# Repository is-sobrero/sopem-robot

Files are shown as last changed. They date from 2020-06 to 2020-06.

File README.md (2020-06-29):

<h1 align="center">SoPEM Robot</h1>
<div align="center">
      <a href="https://www.youtube.com/watch?v=lT5buDZkqcU&t">
     Copertina video
      </a><br>
      <i>Clicca la copertina per guardare il video di presentazione</i><br><br><br>
      
</div>

# Tabella dei contenuti
- [Introduzione](#introduzione)
- [Filosofia Open Source in ogni aspetto](#filosofia-open-source-in-ogni-aspetto)
- [Singoli componenti](#singoli-componenti)
- [Licenza](#licenza)
  - [Autori / Copyright](#autori--copyright)
  - [Dettagli licenza](#dettagli-licenza)

# Introduzione
SoPEM è un robot di tipologia rover studiato appositamente per le finali delle Olimpiadi di Robotica 2020 (anche se in lockdown).
Sfruttando materiali di riciclo, sono stati costruiti 3 robot, dall'aspetto diverso ma tutti e tre volti allo stesso scopo: monitorare i valori di PM10 delle città in modo autonomo con un sensore autocostruito con materiali di riciclo (Un LED infrarosso ricavato da un telecomando e un fotodiodo da un vecchio decoder).

In complemento al robot, è stata sviluppata una applicazione che permette di impostare il percorso da far eseguire al robot e per ottenere i valori di PM10 in tempo reale. 
L'applicazione, sviluppata tramite il framework Flutter, è compatibile con la maggior parte delle piattaforme software attuali: Android, iOS, Web, macOS, Windows e Linux.

Non avendo a disposizione uno strumento di calibrazione professionale, per ottenere valori affidabili è stato creato un modello di machine learning che, addestrato con i dati del sensore e delle stazioni di rilevamento dell’ARPA, è in grado di fornire dati affidabili per il 71%.

# Filosofia Open Source in ogni aspetto
Il robot, oltre ad essere completamente Open Source, è anche sviluppato con strumenti Open Source: da Micropython a Flutter, da KiCad ad Arduino, tutti questi strumenti sono completamente Open e supportati dalla community FOSS e OSHW.

# Singoli componenti
- [Motor Controller](https://github.com/is-sobrero/sopem-robot/tree/master/Software/Motor%20Controller)
- [Robot](https://github.com/is-sobrero/sopem-robot/tree/master/Software/Robot)
- [SoPEM Companion](https://github.com/is-sobrero/sopem-robot/tree/master/Software/sopem_companion)
- [SoPEM Fitter](https://github.com/is-sobrero/sopem-robot/tree/master/Machine%20Learning)
- [Sensore PM10](https://github.com/is-sobrero/sopem-robot/tree/master/Hardware/dust_sensor)

# Licenza
## Autori / Copyright
Copyright 2020 (c) I.S. "A. Sobrero" / SoRobot Team
## Dettagli licenza
Il codice sorgente è rilasciato in licenza secondo GNU General Public License v3.0, che garantisce le quattro regole fondamentali del software libero anche sui fork del firmware del robot.
Le schematiche dell'Hardware sono rilasciate in licenza secondo CERN Open Hardware Licence v1.2, che definisce le condizioni entro cui le schematiche possono essere usate, modificate e distribuite.
Per maggiori dettagli riguardo la licenza, consultare il file [LICENSE](https://github.com/is-sobrero/sopem-robot/blob/master/LICENSE) generale per la repo oppure i file LICENSE per le singole componenti.

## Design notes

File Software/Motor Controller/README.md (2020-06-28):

<h1 align="center">SoPEM Motor Controller</h1>
<div align="center">

</div>

- [Introduzione](#introduzione)
- [Esecuzione](#esecuzione)
  - [Prerequisiti](#prerequisiti)
  - [Flash del firmware](#flash-del-firmware)
- [Licenza](#licenza)
  - [Autori / Copyright](#autori--copyright)
  - [Licenze componenti di terze parti](#licenze-componenti-di-terze-parti)
  - [Dettagli licenza](#dettagli-licenza)
  
# Introduzione
Questa repo contiene il codice sorgente del Motor Controller - L'adattatore I2C per il controllo dei motori.
Il microprocessore utilizzato è un Atmel ATTiny85 cloccato a 16 MHz (pll interno).
# Installazione
## Prerequisiti
Assicurarsi che le definizioni per ATTinyCore siano installate, inoltre impostare l'IDE di Arduino per l'upload su ATTiny85, Clock: Internal 16 MHz.
## Flash del firmware
Caricare il firmware tramite l'IDE di Arduino o tramite un comando avrdude
Una volta assicurati che il firmware sia in esecuzione, impostare i fuses del chip secondo quanto descritto:

     -U lfuse:w:0xf1:m -U hfuse:w:0x57:m -U efuse:w:0xff:m
ATTENZIONE! : Impostando i seguenti fuses, il piedino di reset non funzionerà più come tale ma verrà incluso nei registri IO come PB5, per poter programmare di nuovo il chip non si potrà più usare ISP ma si dovrà usare un programmatore ad alto voltaggio.
# Licenza
## Autori / Copyright
Copyright 2020 (c) I.S. "A. Sobrero" / SoRobot Team
## Licenze componenti di terze parti
| Strumento | Licenza |
|---|---|
| [Arduino](https://github.com/arduino/Arduino) | GNU General Public License v2.0 |
| [avrdude](http://savannah.nongnu.org/projects/avrdude) |GNU General Public License v2.0  |
| [ATTinyCore](https://github.com/SpenceKonde/ATTinyCore) |Non specificata  |
## Dettagli licenza
Il codice sorgente è rilasciato in licenza secondo GNU General Public License v3.0, che garantisce le quattro regole fondamentali del software libero anche sui fork del firmware.
Per maggiori dettagli riguardo la licenza, consultare il file [LICENSE](LICENSE).

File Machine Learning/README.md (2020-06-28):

<h1 align="center">SoPEM Fitter</h1>
<div align="center">
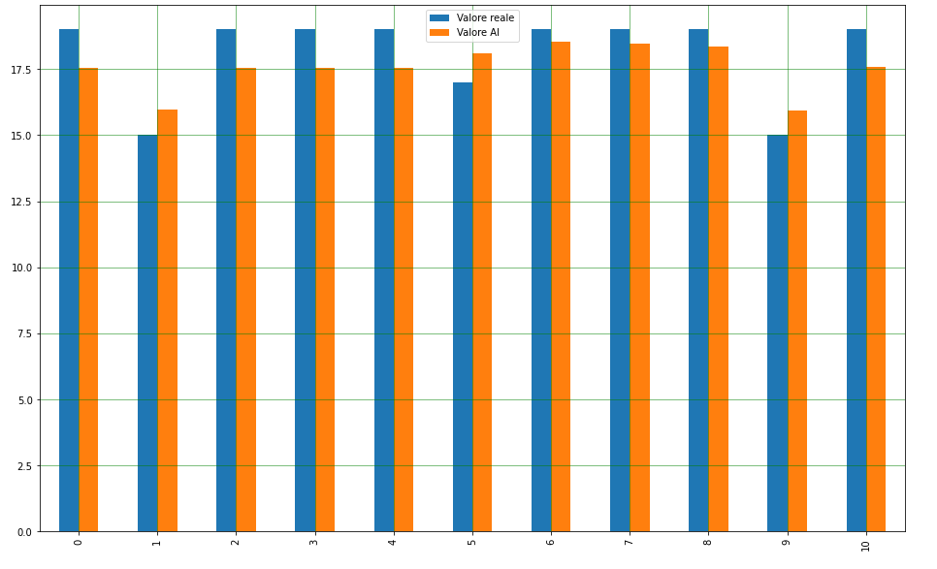
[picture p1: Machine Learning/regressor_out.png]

</div>

# Tabella dei contenuti

- [Introduzione](#introduzione)
- [Esecuzione](#esecuzione)
  - [Inserimento dataset](#inserimento-dataset)
  - [Impostazione config.json](#impostazione-config.json)
- [Licenza](#licenza)
  - [Autori / Copyright](#autori--copyright)
  - [Licenze componenti di terze parti](#licenze-componenti-di-terze-parti)
  - [Dettagli licenza](#dettagli-licenza)

# Introduzione
Questa repo contiene il codice sorgente del SoPEM Fitter - L'addestratore dell'AI per la calibrazione del sensore PM10.

# Esecuzione

Il codice è scritto in Python, e deve essere eseguito su Google Colab. 
Per avviare l'addestramento dell'AI scaricare il file .ipynb ed importarlo in Colab.

## Inserimento dataset
Fitter si basa sui dataset dell'ARPA Piemonte sul particolato per calibrare il sensore, disponibili su [http://www.arpa.piemonte.it/approfondimenti/temi-ambientali/aria/aria/semaforo-qualita-dellaria-pm10](http://www.arpa.piemonte.it/approfondimenti/temi-ambientali/aria/aria/semaforo-qualita-dellaria-pm10). Per inserire i propri dataset, assicurarsi che i riferimenti dell'ARPA siano compatibili con il csv linkato sopra, e assicurarsi inoltre che i dati campionati dal sensore da calibrare siano in un file CSV formattato nel seguente modo:

    PROVINCIA,CITTA,RIFERIMENTO,DATA,ORARIO,AVG_SENSORE
Una volta ottenuti i dati, hostarli su un sito (anche Github va bene) e modificare le seguenti variabili per adeguarle ai dataset caricati:

    ds_real_pm10 = pd.read_csv('https://raw.githubusercontent.com/is-sobrero/pm10-ml/master/datasets/arpa_pm10-20200618%20-%20arpa_pm10-20200618.csv')
    sense_pm10 = pd.read_csv('https://raw.githubusercontent.com/is-sobrero/pm10-ml/master/datasets/pontestura_pm10.csv')
    
Dove `ds_real_pm10` è il dataset dell'ARPA, mentre `sense_pm10` indica i dati del sensore.
## Impostazione config.json
Una volta eseguito lo script, esso restituirà in console un risultato simile al seguente:

    Accuratezza modello: 72.73% 
    Pendenza retta (m): -0.28 
    Termine noto (q): 19.45 
    Esempio di oggetto per il file config.json: 
    { 
      "sensor": { 
          "linear_m": -0.28, 
          "linear_q": 19.45, 
          "reference_voltage": 1.75 
      } 
    }
Oltre a restituire informazioni sul modello appena addestrato, fornisce un esempio di file config.json adattato al modello. Usare i valori indicati nell'output dello script per impostare correttamente il file config.json
# Licenza
## Autori / Copyright
Copyright 2020 (c) I.S. "A. Sobrero" / SoRobot Team
## Licenze componenti di terze parti
| Strumento | Licenza |
|---|---|
| [numpy](https://github.com/numpy/numpy) | BSD 3-Clause |
| [pandas](https://github.com/pandas-dev/pandas) |BSD 3-Clause  |
| [scikit-learn](https://github.com/scikit-learn/scikit-learn) |New BSD  |
| [matplotlib](https://github.com/matplotlib/matplotlib) | PSF Based license
## Dettagli licenza
Il codice sorgente è rilasciato in licenza secondo GNU General Public License v3.0, che garantisce le quattro regole fondamentali del software libero anche sui fork dell'applicazione.
Per maggiori dettagli riguardo la licenza, consultare il file [LICENSE](LICENSE).

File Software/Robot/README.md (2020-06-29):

<h1 align="center">SoPEM Robot Firmware</h1>
<div align="center">

</div>

# Tabella dei contenuti

- [Introduzione](#introduzione)
- [Descrizione del sistema](#descrizione-del-sistema)
	- [Funzionamento](#funzionamento)
	- [Descrizione dei file](#descrizione-dei-file)
- [Installazione](#installazione)
  - [Preparazione di Halocode](#preparazione-di-halocode)
  - [Configurazione ambiente di sviluppo](#configurazione-ambiente-di-sviluppo)
  - [Individuazione della porta seriale di Halocode](#individuazione-della-porta-seriale-di-halocode)
  - [Installazione firmware](#installazione-firmware)
- [Licenza](#licenza)
  - [Autori / Copyright](#autori--copyright)
  - [Licenze componenti di terze parti](#licenze-componenti-di-terze-parti)
  - [Dettagli licenza](#dettagli-licenza)

# Introduzione
Questa repo contiene il codice sorgente del robot SoPEM. 
Nonostante sia principalmente basato su Halocode, il codice essendo scritto in Micropython è facilmente portabile su altre piattaforme con minime modifiche al codice.
Lo scopo principale è di monitorare i valori di PM10 su percorsi di strada preprogrammati sull'applicazione Companion apposita.
# Descrizione del sistema
## Funzionamento
SoPEM è un robot di tipologia rover dedito alla monitorazione dei valori di particolato PM10 nell'aria. Essendo il sensore autocostruito, per ottenere valori affidabili è stato "calibrato" tramite una macchina ad intelligenza artificiale addestrata, oltre coi dati col sensore, coi dati dell'ARPA. Essendo i valori correlati da una funzione lineare, è stato scelto un algoritmo di regressione lineare per elaborare il segnale.
Una volta programmato il movimento, descritto da una stringa JSON inviata tramite MQTT al robot, esso potrà muoversi, previa autorizzazione da parte dell'operatore, eseguendo il percorso programmato. Durante il movimento il robot eseguirà una media dei valori di PM10 rilevati ad ogni movimento, che verrà restituita all'operatore alla fine dell'esecuzione della sequenza.
## Descrizione dei file
Il firmware di SoPEM è estremamente modulare, ogni file è dedito ad una specifica funzione del robot.
 - `main.py`
Questo file gestisce il comportamento generico del Robot, oltre ad essere il file automaticamente eseguito all'avvio di Halocode, esso provvede a connettere Halocode ad Internet, a configurare i motori e il protocollo MQTT per la comunicazione, gestisce il ciclo di comportamento del robot.
- `motors.py`
Questo file è il livello di astrazione tra il codice principale e l'hardware dei motori: `main.py` istanzia una classe di tipologia `motor_controller`, andando ad invocare le funzioni per il movimento degli assi dall'oggetto istanziato.
Se si dispone di un controller dei motori diverso da quello previsto nei sorgenti originali di SoPEM, è necessario modificare solamente questo file per far muovere la propria versione di SoPEM senza alcuna difficoltà particolare.
- `pm10_sense.py`
Questo file è il livello di astrazione tra il codice principale e il sensore di particolato: `main.py` istanzia una classe di tipologia `pm10_sensor`, andando ad invocare le funzioni per la lettura del valore di particolato dall'oggetto istanziato. 
Se si dispone di un sensore più avanzato rispetto a quello previsto nei sorgenti originali di SoPEM (quindi senza bisogno di regressiore lineare per l'elaborazione del valore), è necessario modificare solamente questo file per renderlo compatibile com SoPEM.
- `config.json`
Questo file contiene la configurazione del robot, dalle credenziali della rete wifi a quelle del broker MQTT, dai topic dedicati al robot agli indirizzi I2C delle periferiche. Per configurare SoPEM per le proprie esigenze, spesso è occorrente modificare solo questo file.
- `umqttsimple.py`
Questo file contiene la libreria umqtt.simple, non modificare questo file.

# Installazione
## Preparazione di Halocode
Il firmware originale di Halocode è limitato alla programmazione con Mblock, per eseguire il software di SoPEM bisogna, prima di tutto, installare il firmware adattato per l'editor Mu, seguire la guida [presente a questo link](http://docs.makeblock.com/halocode/en/tutorials/use-python-mu.html) per configurare Halocode.
Una volta installato il firmware custom, caricare un programma qualsiasi tramite l'editor Mu (Importante! altrimenti il codice main.py non verrà mai eseguito all'avvio)

## Configurazione ambiente di sviluppo
Per installare il codice su Halocode assicurarsi di avere i seguenti programmi installati:

 - Python3
 - pip
 - ampy
 - GNU Make tools
 - git

Una volta che si è sicuri di avere i seguenti programmi installati, clonare la repo con git e recarsi nella cartella coi sorgenti del SW di SoPEM
Avviare una finestra di terminale e lanciare il seguente comando:

    make check

Se un programma è mancante maketools lo segnalerà.
## Individuazione della porta seriale di Halocode
Collegare Halocode al computer.
Da qui, in base al sistema operativo host seguire le seguenti procedure:

- Windows
	- Avviare Gestione dispositivi, da qui, sotto la voce "Porte Seriali COM" individuare la porta seriale associata ad Halocode (inizia con COM)
- Linux
	- Avviare una finestra del terminale e lanciare il seguente comando:
	- `ls /dev | grep "tty."`
	- Annotarsi la porta seriale corrispondente ad Halocode (inizia con /dev/ttyUSB)
- macOS
	- Avviare una finestra del terminale e lanciare il seguente comando:
	- `ls /dev | grep "cu."`
	- Annotarsi la porta seriale corrispondente ad Halocode (inizia con /dev/cu.wchusbmodem)

## Installazione firmware
 Una volta individuata la porta seriale di Halocode, avviare l'installazione tramite il comando

    make install port="PORTA_SERIALE"

Dove PORTA_SERIALE è la stringa precedentemente individuata.
Se la procedura è andata a buon fine, è possibile scollegare e ricollegare Halocode al computer, se il terminale mostra errori a schermo, eseguire di nuovo il comando make install (non è il metodo ufficiale per caricare file su Halocode, sporadicamente ha errori di sincronizzazione con la REPL).
# Licenza
## Autori / Copyright
Copyright 2020 (c) I.S. "A. Sobrero" / SoRobot Team
## Licenze componenti di terze parti
| Strumento | Licenza |
|---|---|
| [Micropython](https://github.com/micropython/micropython) | MIT License |
| [umqtt.simple](https://github.com/micropython/micropython-lib/tree/master/umqtt.simple) | MIT License  |
| [ampy](https://github.com/scientifichackers/ampy) | MIT License  |
## Dettagli licenza
Il codice sorgente è rilasciato in licenza secondo GNU General Public License v3.0, che garantisce le quattro regole fondamentali del software libero anche sui fork del firmware del robot.
Per maggiori dettagli riguardo la licenza, consultare il file [LICENSE](LICENSE).

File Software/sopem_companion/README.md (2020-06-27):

<h1 align="center">SoPEM Companion</h1>

<div align="center">
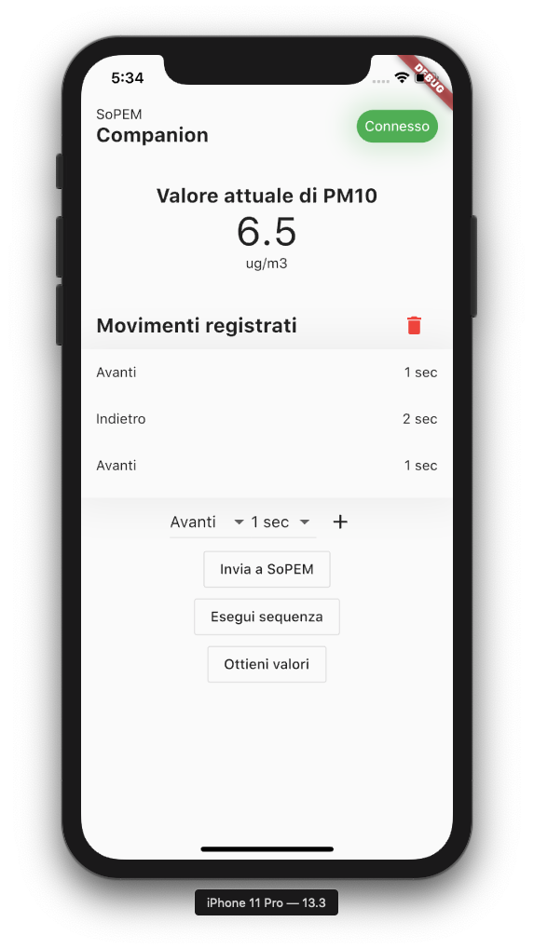
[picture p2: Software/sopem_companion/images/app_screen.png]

</div>

# Tabella dei contenuti

- [Introduzione](#introduzione)
- [Installazione](#installazione)
  - [Framework Flutter](#framework-flutter)
  - [Clonazione del repository](#clonazione-del-repository)
  - [Compilazione app](#compilazione-app)
- [Licenza](#licenza)
  - [Autori / Copyright](#autori--copyright)
  - [Licenze componenti di terze parti](#licenze-componenti-di-terze-parti)
  - [Dettagli licenza](#dettagli-licenza)

# Introduzione
Questa repo contiene il codice sorgente del SoPEM Companion - L'app per programmare i movimenti di SoPEM.

La compatibilità cross-platform è garantita da Flutter, framework open-source sviluppato da Google per permettere l'esecuzione della stessa app, dalla stessa base di codice, su molteplici piattaforme.

# Installazione
L'installazione di SoPEM Companion prevede diversi step, sia per preparare l'ambiente di sviluppo che per preparare il dispositivo di destinazione.

## Framework Flutter
SoPEM Companion è basato completamente sul framework Flutter, per procedere con la compilazione dell'applicazione bisogna preparare l'ambiente di sviluppo Flutter nel computer.

L'ambiente Flutter è compatibile con la maggior parte dei sistemi operativi desktop: Windows, macOS, Linux e Chrome OS.

Predisporre l'ambiente di sviluppo secondo le guide linea descritte dalla guida ufficiale: https://flutter.dev/docs/get-started/install

Verificare che l'ambiente di sviluppo sia configurato correttamente lanciando il comando

    flutter doctor

da terminale, se il programma segnala errori, utilizzare le guide ufficiali di Google per risolverli.

## Clonazione del repository
Assicurarsi che git sia installato sul computer.

Clonare la repo tramite i comandi di Github.

## Compilazione app
Indipendentemente dal sistema operativo di destinazione, è consigliabile utilizzare Android Studio come ambiente di sviluppo, essendo attualmente l'IDE supportato maggiormente per lo sviluppo Flutter.
Bisognerà inoltre installare il plugin Flutter e Dart per Android Studio.

In base al sistema operativo di destinazione, bisognerà installare diversi strumenti:

- Android
  - Android SDK (incluso in Android Studio)
  - Dispositivo Android con le impostazioni da sviluppatore abilitate
  - Java JDK
- iOS
  - Xcode 11 (da App Store, disponibile solo su macOS)
  - CocoaPods

Se si sta compilando SoPEM Companion su macOS, dopo aver installato Xcode 11 eseguire i seguenti comandi da terminale:

    sudo xcode-select --switch /Applications/Xcode.app/Contents/Developer
    sudo xcodebuild -runFirstLaunch
    sudo xcodebuild -license

Testare la configurazione di macOS lanciando il seguente comando (avvio del simulatore)

    open -a Simulator

Una volta configurato l'ambiente di sviluppo, aprire il progetto con Android Studio, aprire il file pubspeck.yaml e cliccare "Packages get", qui Android Studio sincronizzerà il progetto con le dipendenze richieste.

Ora è possibile compilare l'applicazione: selezionare nel menù in alto a destra il dispositivo di destinazione, dopo averlo collegato al computer, e cliccare dal menù "Run" l'opzione "Flutter run main.dart in Release mode".
Il processo di compilazione è lungo, soprattutto la prima volta, attendere col dispositivo di destinazione collegato al computer per tutta la durata dell'operazione.

# Licenza
## Autori / Copyright
Copyright 2020 (c) I.S. "A. Sobrero" / SoRobot Team
## Licenze componenti di terze parti
| Strumento | Licenza |
|---|---|
| [Flutter](https://github.com/flutter/flutter) | BSD 3-Clause |
| [mqtt_client](https://github.com/shamblett/mqtt_client) | MIT License  |
## Dettagli licenza
Il codice sorgente è rilasciato in licenza secondo GNU General Public License v3.0, che garantisce le quattro regole fondamentali del software libero anche sui fork dell'applicazione.
Per maggiori dettagli riguardo la licenza, consultare il file [LICENSE](LICENSE).

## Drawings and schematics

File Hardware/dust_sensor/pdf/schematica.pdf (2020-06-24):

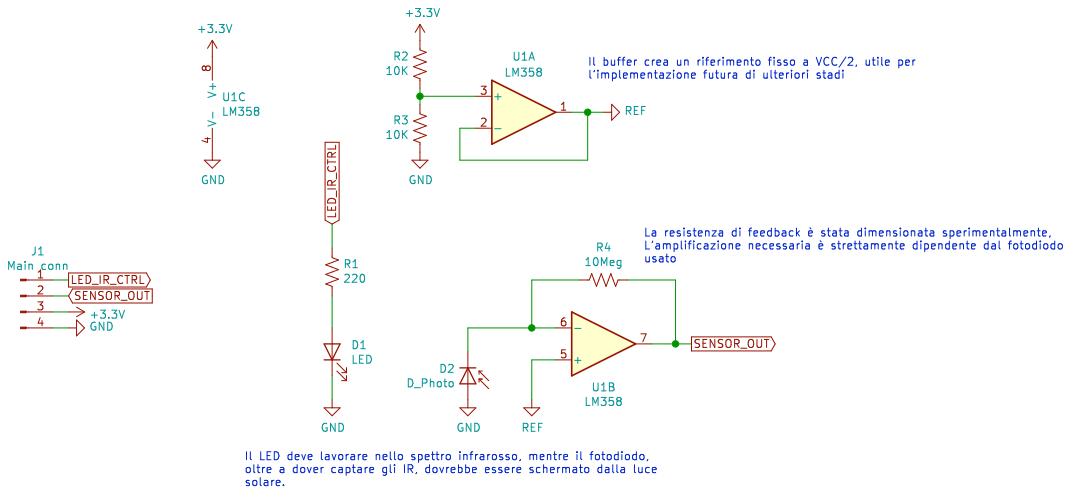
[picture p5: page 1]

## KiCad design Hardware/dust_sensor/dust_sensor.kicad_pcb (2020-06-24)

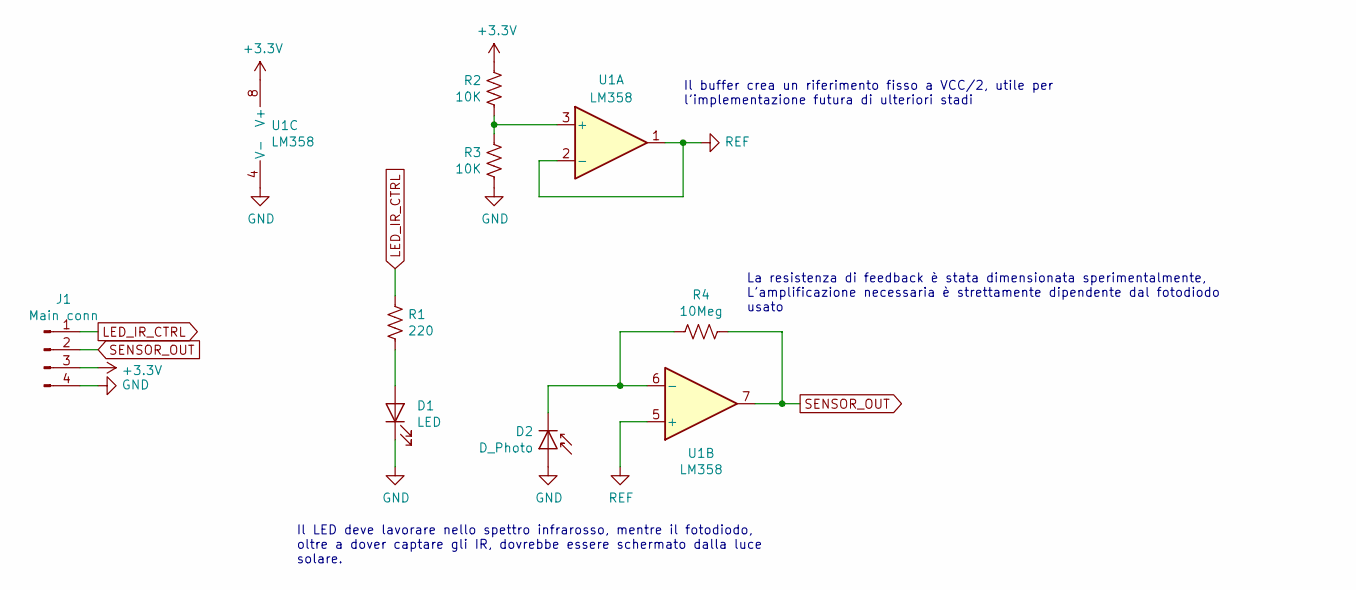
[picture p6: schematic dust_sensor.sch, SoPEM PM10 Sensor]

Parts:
D1: LED; LED_D5.0mm_Horizontal_O1.27mm_Z3.0mm_Clear
D2: D_Photo; LED_D5.0mm_Horizontal_O1.27mm_Z3.0mm_IRBlack
J1: Main conn; PinHeader_1x04_P2.54mm_Vertical
R1: 220; R_Axial_DIN0207_L6.3mm_D2.5mm_P7.62mm_Horizontal
R2, R3: 10K; R_Axial_DIN0207_L6.3mm_D2.5mm_P7.62mm_Horizontal
R4: 10Meg; R_Axial_DIN0207_L6.3mm_D2.5mm_P7.62mm_Horizontal
U1: LM358; DIP-8_W7.62mm_LongPads

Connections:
+3V3: J1.3, R2.2, U1.8 (V+)
GND: D1.1 (K), D2.2 (A), J1.4, R3.1, U1.4 (V-)
LED_IR_CTRL: J1.1, R1.2
unnamed: D1.2 (A), R1.1
unnamed: D2.1 (K), R4.2, U1.6 (-)
unnamed: R2.1, R3.2, U1.3 (+)
REF: U1.1, U1.2 (-), U1.5 (+)
SENSOR_OUT: J1.2, R4.1, U1.7

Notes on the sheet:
Il buffer crea un riferimento fisso a VCC/2, utile per l’implementazione futura di ulteriori stadi
La resistenza di feedback è stata dimensionata sperimentalmente, L’amplificazione necessaria è strettamente dipendente dal fotodiodo usato
Il LED deve lavorare nello spettro infrarosso, mentre il fotodiodo, oltre a dover captare gli IR, dovrebbe essere schermato dalla luce solare.

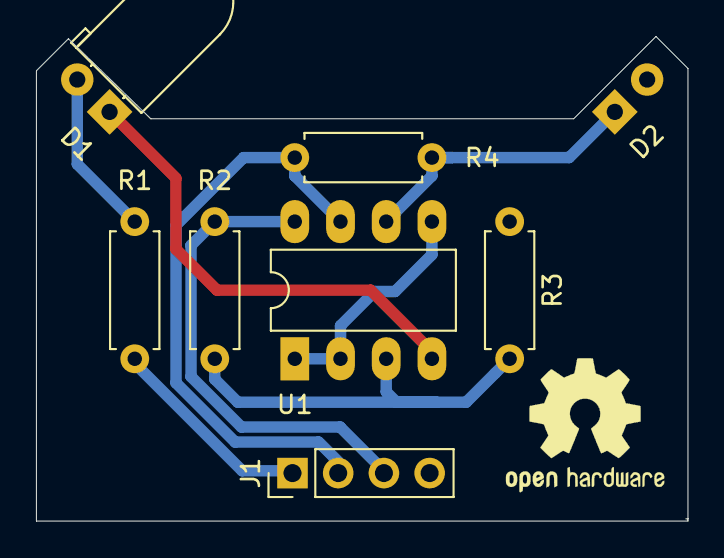
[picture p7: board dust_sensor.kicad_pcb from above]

Board: 2 copper layers, 36.2 x 26.9 mm, 8 parts (1 on the bottom side), 8 nets.

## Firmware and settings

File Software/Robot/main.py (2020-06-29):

# Copyright 2020 I.S. "A. Sobrero" - SoRobot Team. All rights reserved.
# Use of this source code is governed by the GPL 3.0 license that can be
# found in the LICENSE file.

# Svuota la RAM dalla spazzatura all'avvio dello script
# Utile durante il debug se si avvia lo script dalla REPL
import gc, halo
gc.collect()

# Workaround per usare i pin di halocode con machine,
# il firmware di default sembra fare pasticci sui pin,
# facendo così sembra l'unico modo per rimediare
halo.pin0.write_digital(0)
halo.pin1.write_digital(0)
halo.pin2.write_digital(0)
halo.pin3.write_digital(0)

import machine
from machine import Pin
import ujson
import network
import time
from umqttsimple import MQTTClient
import ubinascii
from motors import motor_controller
from pm10_sense import pm10_sensor

# D0 = Pin 2
# D1 = Pin 15
# A2 = Pin 33
# A3 = Pin 32

# Carica la configurazione SW
with open("config.json") as cfg:
	config = ujson.loads(cfg.read())

net = network.WLAN(network.STA_IF)
machine_id = machine.unique_id()
client_id = ubinascii.hexlify(machine_id).decode('utf-8')

# Istanzia la classe del motor controller
mc = motor_controller(21, 22, 0x77)

# Istanzia la classe del sensore pm10
pm10 = pm10_sensor(2, 33) # cambiare pin

sequence_str = ""

# funzione per gestire gli errori
def on_error(desc):
	halo.led.show_ring("black black red red red red red red red black black black") # :(
	print("[E] " + desc)
	print("[I] Uscita dallo script")
	quit()

def network_connect():
	# se già connesso è inutile fare tutta la procedura
	if net.isconnected() == True:
		print("SoPEM connesso, ifconfig:")
		print(net.ifconfig())
		return

	# Cerca di connettersi alla rete wifi, se fallisce
	# visualizza una faccia triste
	net.active(True)
	net.connect(config["wifi"]["ssid"], config["wifi"]["password"])

    # timeout di connessione
	timeout = time.time() + 30

	while not net.isconnected():
		# se non riesce a connettersi entro 30 secondi,
		# esce dallo script
		halo.led.show_animation('meteor')
		if time.time() > timeout:
			on_error("Impossibile connettersi alla rete wifi")

	print("SoPEM connesso, ifconfig:")
	print(net.ifconfig())

def run_sequence(response):
	global mc, pm10, client, config
	average_pm10 = 0
	sequence = ujson.loads(response)
	for movement in sequence:
		if movement["direction"] == 0:
			print("fwd")
	    	mc.motor_forward()
		if movement["direction"] == 1:
			print("rev")
			mc.motor_reverse()
		if movement["direction"] == 2:
			print("dx")
			mc.motor_right()
		if movement["direction"] == 3:
			print("sx")
			mc.motor_left()
		time.sleep(movement["duration"])
		mc.motor_stop()
		average_pm10 += pm10.get_pm10()

	average_pm10 /= len(sequence)	
	send_topic = str.encode(config["mqtt"]["topics"]["pm10"])
	send_msg = str(average_pm10).encode('utf-8')
	client.publish(send_topic, send_msg)

def get_pm10(send_to_broker = False):
	global client, config, pm10
	
	concentration = pm10.get_pm10()
	
	if send_to_broker:
		send_topic = str.encode(config["mqtt"]["topics"]["pm10"])
		send_msg = str(concentration).encode('utf-8')
		print(send_topic)
		client.publish(send_topic, send_msg)

def on_message(topic, msg):
	global sequence_str, config
	msg_str = msg.decode("utf-8")
	topic_str = topic.decode("utf-8")
	print(topic)

	if topic_str == config["mqtt"]["topics"]["config"]:
		if msg_str == "run" and not sequence_str == "":
			run_sequence(sequence_str)
		if msg_str == "get":
			get_pm10(True)

	if topic_str == config["mqtt"]["topics"]["sequence"]:
		sequence_str = msg_str

def get_client(client_id, uri, uname, upass):
	client = MQTTClient(client_id, uri)
	client.set_callback(on_message)
	client.connect()
	print("Connesso al broker")
	return client

# Configurazione iniziale del robot
network_connect()

if not mc.discovery():
	on_error("Controller dei motori non connesso!")

try:
	client = get_client(
		client_id,
		config["mqtt"]["broker"],
		config["mqtt"]["username"],
		config["mqtt"]["password"]
	)
	client.subscribe(config["mqtt"]["topics"]["config"])
	client.subscribe(config["mqtt"]["topics"]["sequence"])
except OSError as e:
	on_error(e.args[0])

halo.led.show_ring("green green green black black black black black green green green green") # :)

while True:
	try:
		client.check_msg()
	except OSError as e:
		print(e.args[0])

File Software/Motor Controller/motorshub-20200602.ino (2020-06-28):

// Copyright 2020 I.S. "A. Sobrero". All rights reserved.
// Use of this source code is governed by the GPL 3.0 license that can be
// found in the LICENSE file.

#define CFG_I2C_DEFAULT_ADDRESS 0x77

#define CFG_I2C_DESTINATION_MOTOR_A 0x0A
#define CFG_I2C_DESTINATION_MOTOR_B 0x0B
#define CFG_I2C_COMMAND_MOTOR_STOP 0x01
#define CFG_I2C_COMMAND_MOTOR_FWD 0x02
#define CFG_I2C_COMMAND_MOTOR_REV 0x03

#define CFG_HBRIDGE_MA1 1
#define CFG_HBRIDGE_MA2 3
#define CFG_HBRIDGE_MB1 4
#define CFG_HBRIDGE_MB2 5

#include <Wire.h>

void setup() {
  pinMode(CFG_HBRIDGE_MA1, OUTPUT);
  pinMode(CFG_HBRIDGE_MA2, OUTPUT);
  pinMode(CFG_HBRIDGE_MB1, OUTPUT);
  pinMode(CFG_HBRIDGE_MB2, OUTPUT);
  Wire.begin(CFG_I2C_DEFAULT_ADDRESS);
  Wire.onReceive(receiveISR);
}

void loop() {
  // watchdog trigger!
  delay(100);
}

void receiveISR(int len){
  while(Wire.available() > 0){
    uint8_t data = Wire.read();
    
    uint8_t destination = data >> 4;
    uint8_t command = data & 0x0F;

    if (destination == CFG_I2C_DESTINATION_MOTOR_A){
      if (command == CFG_I2C_COMMAND_MOTOR_STOP){
        digitalWrite(CFG_HBRIDGE_MA1, HIGH);
        digitalWrite(CFG_HBRIDGE_MA2, HIGH);
      }
      if (command == CFG_I2C_COMMAND_MOTOR_FWD){
        digitalWrite(CFG_HBRIDGE_MA1, LOW);
        digitalWrite(CFG_HBRIDGE_MA2, HIGH);
      }
      if (command == CFG_I2C_COMMAND_MOTOR_REV){
        digitalWrite(CFG_HBRIDGE_MA1, HIGH);
        digitalWrite(CFG_HBRIDGE_MA2, LOW);
      }
    }

    if (destination == CFG_I2C_DESTINATION_MOTOR_B){
      if (command == CFG_I2C_COMMAND_MOTOR_STOP){
        digitalWrite(CFG_HBRIDGE_MB1, HIGH);
        digitalWrite(CFG_HBRIDGE_MB2, HIGH);
      }
      if (command == CFG_I2C_COMMAND_MOTOR_FWD){
        digitalWrite(CFG_HBRIDGE_MB1, LOW);
        digitalWrite(CFG_HBRIDGE_MB2, HIGH);
      }
      if (command == CFG_I2C_COMMAND_MOTOR_REV){
        digitalWrite(CFG_HBRIDGE_MB1, HIGH);
        digitalWrite(CFG_HBRIDGE_MB2, LOW);
      }
    }
  }
}

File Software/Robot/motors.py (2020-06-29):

# Copyright 2020 I.S. "A. Sobrero" - SoRobot Team. All rights reserved.
# Use of this source code is governed by the GPL 3.0 license that can be
# found in the LICENSE file.

import machine
from machine import Pin
import ujson

class motor_controller:
	def __init__(self, sda, scl, addr):
		self.sda = Pin(sda)
		self.scl = Pin(scl)
		self.i2c = machine.I2C(scl=self.scl, sda=self.sda)

		self.motorAddr = addr

	def discovery(self):
		connected_devices = self.i2c.scan()
		return self.motorAddr in connected_devices

	def motor_forward(self):
		self.i2c.writeto(self.motorAddr, b'\xA2')
		self.i2c.writeto(self.motorAddr, b'\xB2')

	def motor_reverse(self):
		self.i2c.writeto(self.motorAddr, b'\xA3')
		self.i2c.writeto(self.motorAddr, b'\xA3')

	def motor_left(self):
		self.i2c.writeto(self.motorAddr, b'\xA3')
		self.i2c.writeto(self.motorAddr, b'\xB2')

	def motor_right(self):
		self.i2c.writeto(self.motorAddr, b'\xA2')
		self.i2c.writeto(self.motorAddr, b'\xB3')

	def motor_stop(self):
		self.i2c.writeto(self.motorAddr, b'\xA1')
		self.i2c.writeto(self.motorAddr, b'\xA1')

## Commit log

2020-06-24 Uploaded dust sensor documentation
    [dust_sensor.kicad_pcb, dust_sensor.sch]
2020-06-28 Uploaded ML sources
    [arpa_pm10-20200625.csv, pontestura_pm10.csv]
2020-06-28 Uploaded motor controller sources
